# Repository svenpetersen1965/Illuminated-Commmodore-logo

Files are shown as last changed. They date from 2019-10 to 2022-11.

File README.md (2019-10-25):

# Illuminated-Commodore-logo
This is, what you need for your hobby retro computer projects: a Commodore logo, which is illuminated with two LEDs!

This project consists out of a 3D printed logo and a PCB that contains the LEDs and limiting resistors. 

The 3D print is made from three parts:
1. The illuminated body, which is printed with transparent PLA
2. A face plate
3. A reflector

The transparent part is printed with 100% infill (important!). I have printed it upright (on the side with the LED holes). 

There are two types of face plates: one with rounded corners and one without. It should be printed from a material, that is not any translucent. Black is a good color. White is not so suitable. 

The orientation of the reflector while printng is not so important. It should be printed with a white filament.

The Fusion 360 design is contained in this project.

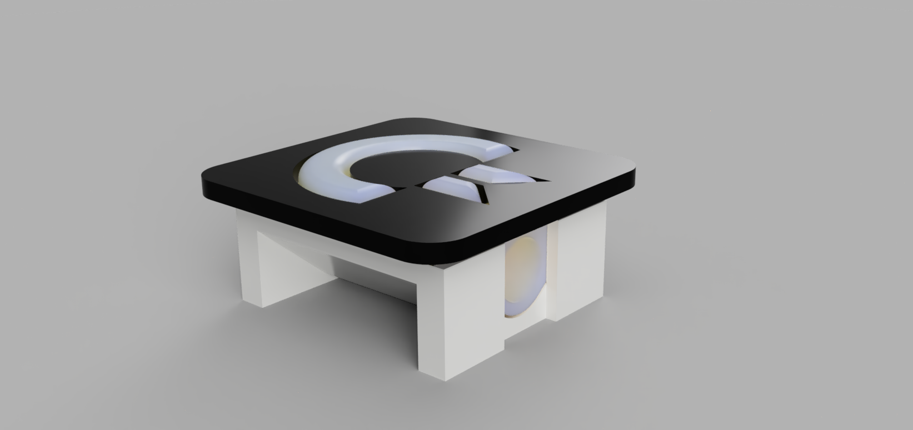
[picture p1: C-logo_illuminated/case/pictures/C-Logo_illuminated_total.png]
Commodore Logo


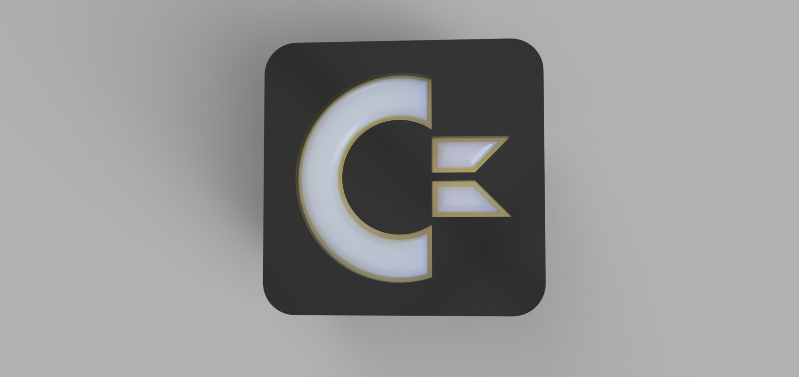
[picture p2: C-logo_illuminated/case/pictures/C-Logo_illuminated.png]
Commodore Logo


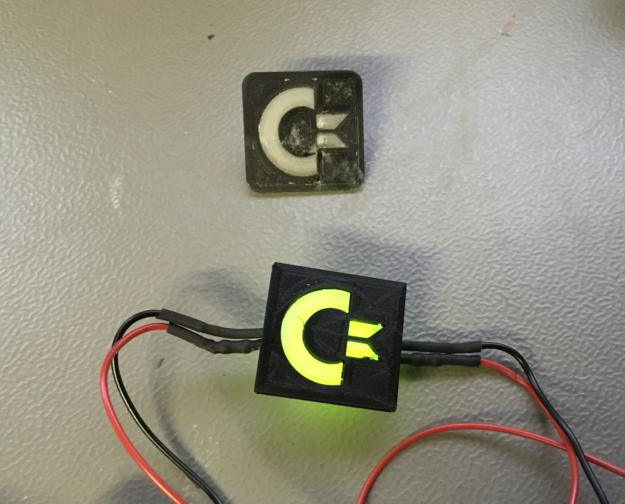
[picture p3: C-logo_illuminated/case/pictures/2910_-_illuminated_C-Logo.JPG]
Commodore Logo


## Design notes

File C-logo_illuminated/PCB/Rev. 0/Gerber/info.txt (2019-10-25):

      
       Board: C-logo
       Rev.:  0
  
       Files:
       ======
  
       All Gerber files are generated in extended gerber format (RS274X)
       *.TOP        : Film top copper
       *.BOT        :  -"- bottom copper
       *.STC        :  -"- top soldermask 
       *.STS        :  -"- bottom soldermask
       *.PLC        :  -"- silk screen top
       *.PLS        :  -"- silk screen bottom
       *.DK         : Drills plated Through (Excellon)
       *.NDK        : Drills not plated Through (Excellon)
       *.OUT        : Board outline

       Board Size:
       ===========
       Length     :   30.0 mm
       Width      :   25.4 mm
       Thickness  :   1.6 mm
       Material   :   FR 4
       Copper     :   35 um
       Surface    :   HASL
       
       Remarks:
       ========
       Width >= 8mil
       Distance >= 6mil
       Drill >= 0.6mm

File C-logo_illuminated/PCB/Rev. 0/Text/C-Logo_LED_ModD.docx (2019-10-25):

Illuminated Commodore Logo Rev. 0
Module description

The Commodore Logo is a sort of fan art and the purpose is the use in hobby projects. A transparent 3D printed body is illuminated with two LEDs and masked with a face plate, that is designed to the measures defined in a document about the Commodore C= logo.

The PCB contains two 5mm LEDs, which are sufficient to illuminate the logo. These LEDs require a current limiting resistor each, which is also contained on the PCB.

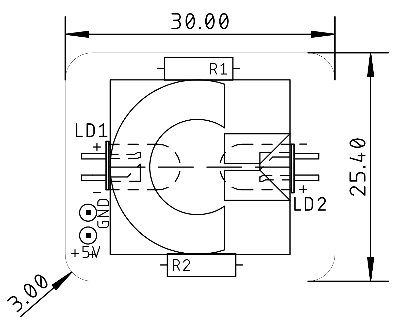
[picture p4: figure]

Figure 1: Dimensions of the PCB

For 5V supply voltage and a standard red, green or yellow LED, a value of 330Ω is sufficient. For other LEDs, like a blue or white LED, or other supply voltages or currents, the resistor value has to be calculated.

R_(LED) =(U_(supply) -U_(f, LED))/(I_(f,LED))

RLED: current limiting resistor for the LED
Usupply: Supply voltage
Uf,LED: Forward voltage of the LED
If, LED: Forward current of the LED

The forward voltage and current can be found in the data sheet of the LED. That is the voltage drop over the LED, when it is conducting and the current should be below the maximum rating. A typical value for a standard LED is Uf, LED is 1.8V and for the current If,LED is 10mA. This results in

R_(LED) =(5V-1.8V)/(0.010A)=320Ω≈330Ω

The available resistor value closest to 320Ω is 330Ω. The resistors do not require a very accurate value, so it is no problem to use what is available. A range of ±10% is ok for this purpose.

A blue LED with a forward voltage of 3.2V and a forward current of 20mA will require a forward resistor, that is

R_(LED) =(5V-3.2V)/(0.020A)=90Ω≈91Ω

A 91Ω resistor is sufficient. Notice: The forward voltages of blue LEDs are varying and it is required to look it up for the specific LED. The same applies for white LEDs.

C-Logo_LED_ModD.docx 25.10.2019 11:45 Drafted by Sven Petersen Page 2 of 2 Doc.-No.: 000-6-00-00

C-Logo_LED_ModD.docx 25.10.2019 11:45 Drafted by Sven Petersen Page 1 of 1 Doc.-No.: 135-6-01-00

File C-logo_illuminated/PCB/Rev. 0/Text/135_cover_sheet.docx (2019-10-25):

Project Documentation

Illuminated Commodore Logo

Project number: 135

Revision: 0

Date: 25.10.2019

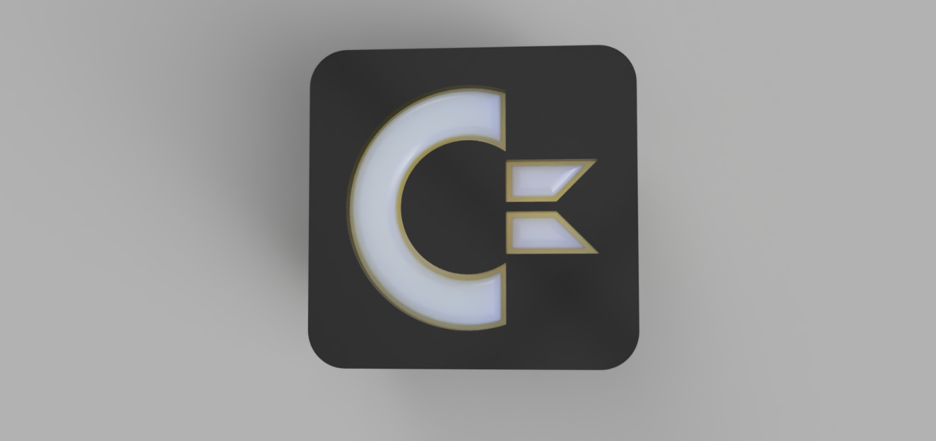
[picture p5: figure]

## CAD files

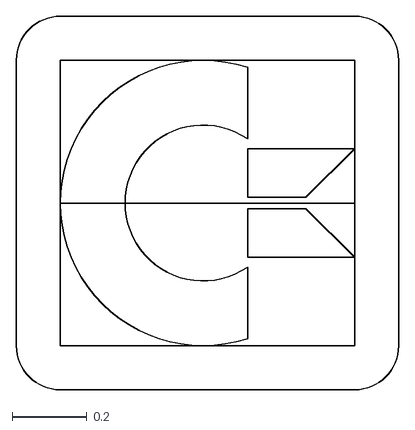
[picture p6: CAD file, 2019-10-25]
C-logo_illuminated/case/dxf/c-logo_used.DXF
1.02 x 1.00

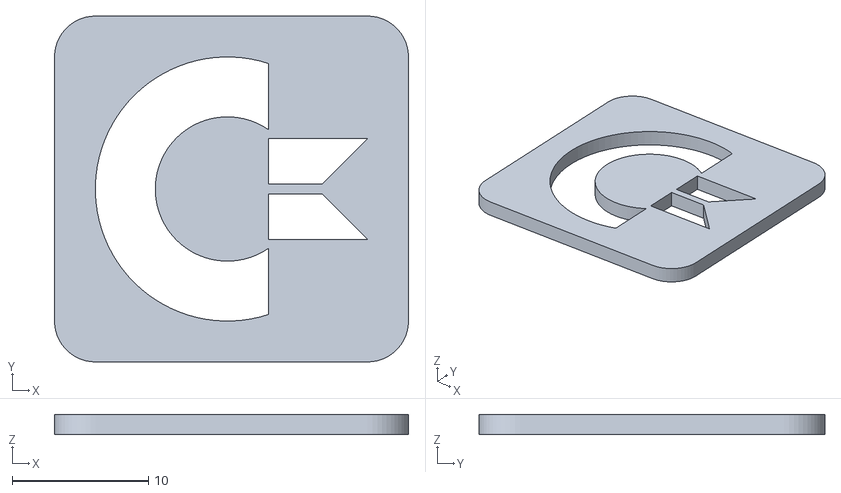
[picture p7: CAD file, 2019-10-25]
C-logo_illuminated/case/stl/face plate rounded.stl
26.0 x 25.4 x 1.50

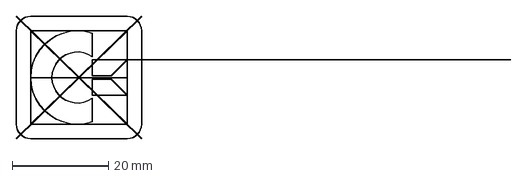
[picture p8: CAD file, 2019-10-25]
C-logo_illuminated/case/dxf/c-logo.dxf
102.6 x 25.4 mm

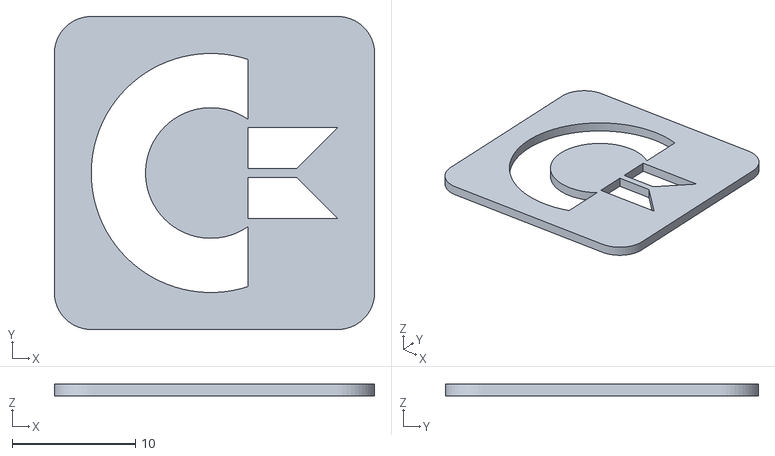
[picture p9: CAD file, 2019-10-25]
C-logo_illuminated/case/stl/panel.stl
26.0 x 25.4 x 1.00

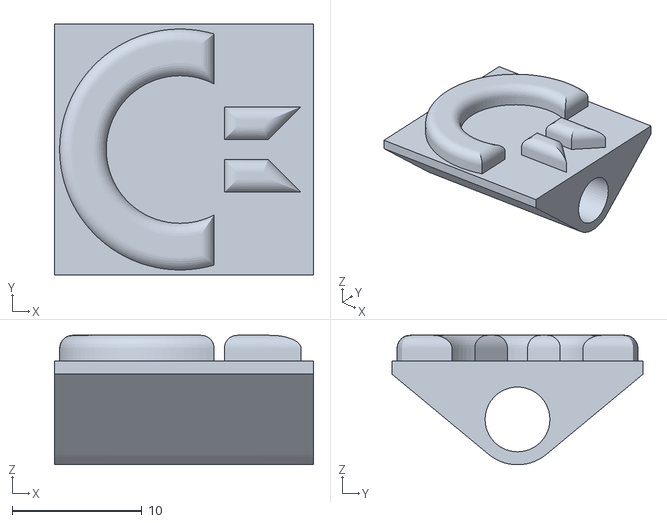
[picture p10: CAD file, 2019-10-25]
C-logo_illuminated/case/stl/illuminated body.stl
20.0 x 19.4 x 10.0

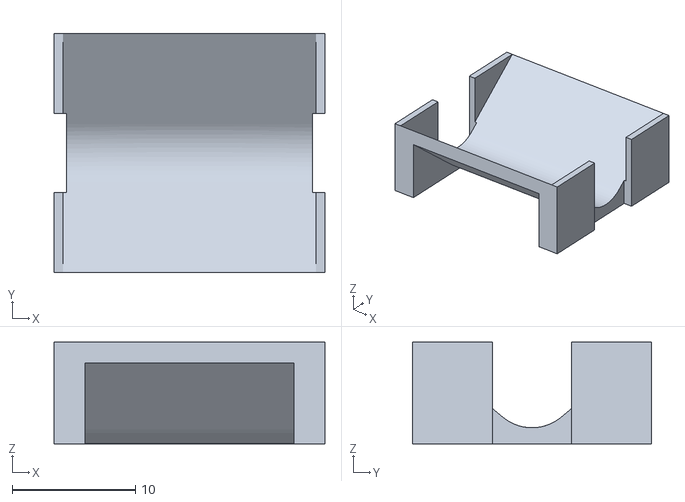
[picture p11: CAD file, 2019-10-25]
C-logo_illuminated/case/stl/reflector.stl
22.0 x 19.4 x 8.24

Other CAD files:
C-logo_illuminated/case/stl/face plate 1.5.stl
C-logo_illuminated/case/fusion 360/C-Logo_illuminated v12.f3d

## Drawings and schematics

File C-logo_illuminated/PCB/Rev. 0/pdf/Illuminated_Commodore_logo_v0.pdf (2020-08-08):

# Project Documentation

## Illuminated Commodore Logo

## Project number: 135

## Revision: 0

## Date: 25.10.2019

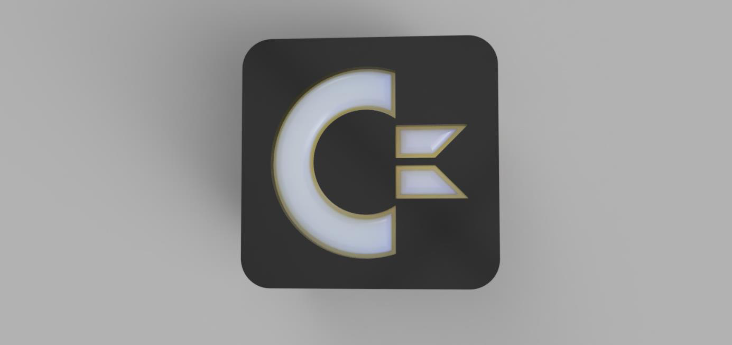
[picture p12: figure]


C-Logo_LED_ModD.docx | | 25.10.2019 11:45
Drafted by Sven Petersen | Page 1 of 1 | Doc.-No.: 135-6-01-00

### Illuminated Commodore Logo Rev. 0

### Module description

The Commodore Logo is a sort of fan art and the purpose is the use in hobby projects. A transparent 3D printed body is illuminated with two LEDs and masked with a face plate, that is designed to the measures defined in a document about the Commodore C= logo.

The PCB contains two 5mm LEDs, which are sufficient to illuminate the logo. These LEDs require a current limiting resistor each, which is also contained on the PCB.

Figure 1: Dimensions of the PCB
For 5V supply voltage and a standard red, green or yellow LED, a value of 330Ω is sufficient. For other LEDs, like a blue or white LED, or other supply voltages or currents, the resistor value has to be calculated.

# RLED =

# Usupply − Uf,LED

# If,LED

RLED: current limiting resistor for the LED Usupply: Supply voltage
Uf,LED: Forward voltage of the LED
If, LED: Forward current of the LED

The forward voltage and current can be found in the data sheet of the LED. That is the voltage drop over the LED, when it is conducting and the current should be below the maximum rating. A typical value for a standard LED is Uf, LED is 1.8V and for the current If,LED is 10mA. This results in

# RLED =

5V − 1.8V

# 0.010A = 320Ω ≈ 330Ω

The available resistor value closest to 320Ω is 330Ω. The resistors do not require a very accurate value, so it is no problem to use what is available. A range of ±10% is ok for this purpose.

A blue LED with a forward voltage of 3.2V and a forward current of 20mA will require a forward resistor, that is

# RLED =

5V − 3.2V
0.020A

= 90Ω ≈ 91Ω

A 91Ω resistor is sufficient. Notice: The forward voltages of blue LEDs are varying and it is required to look it up for the specific LED. The same applies for white LEDs.

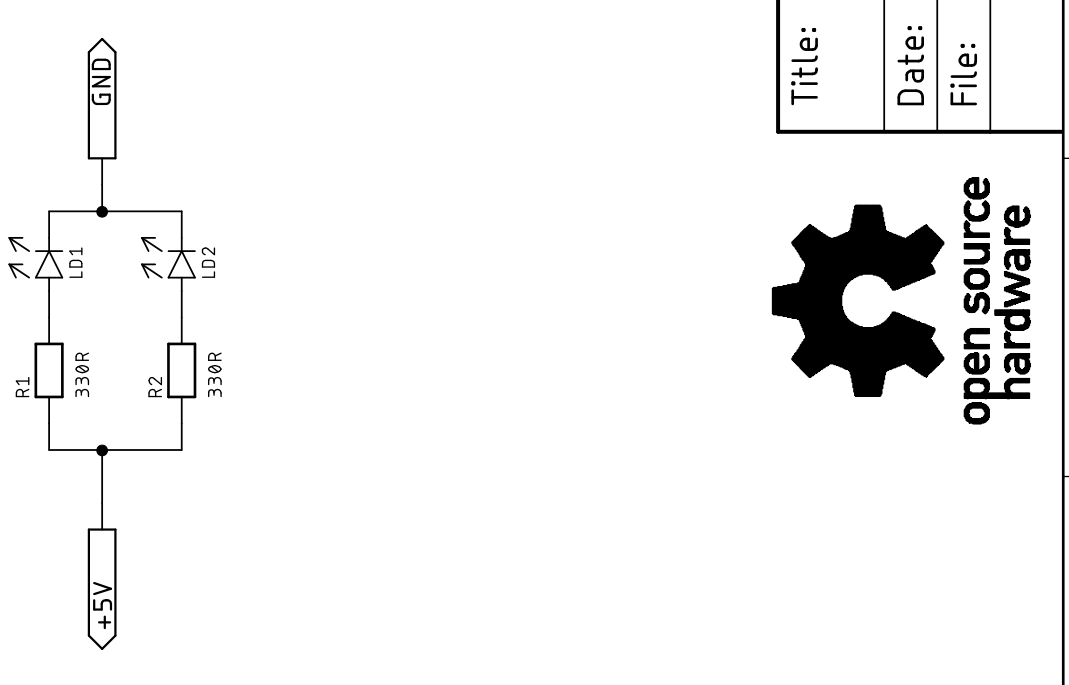
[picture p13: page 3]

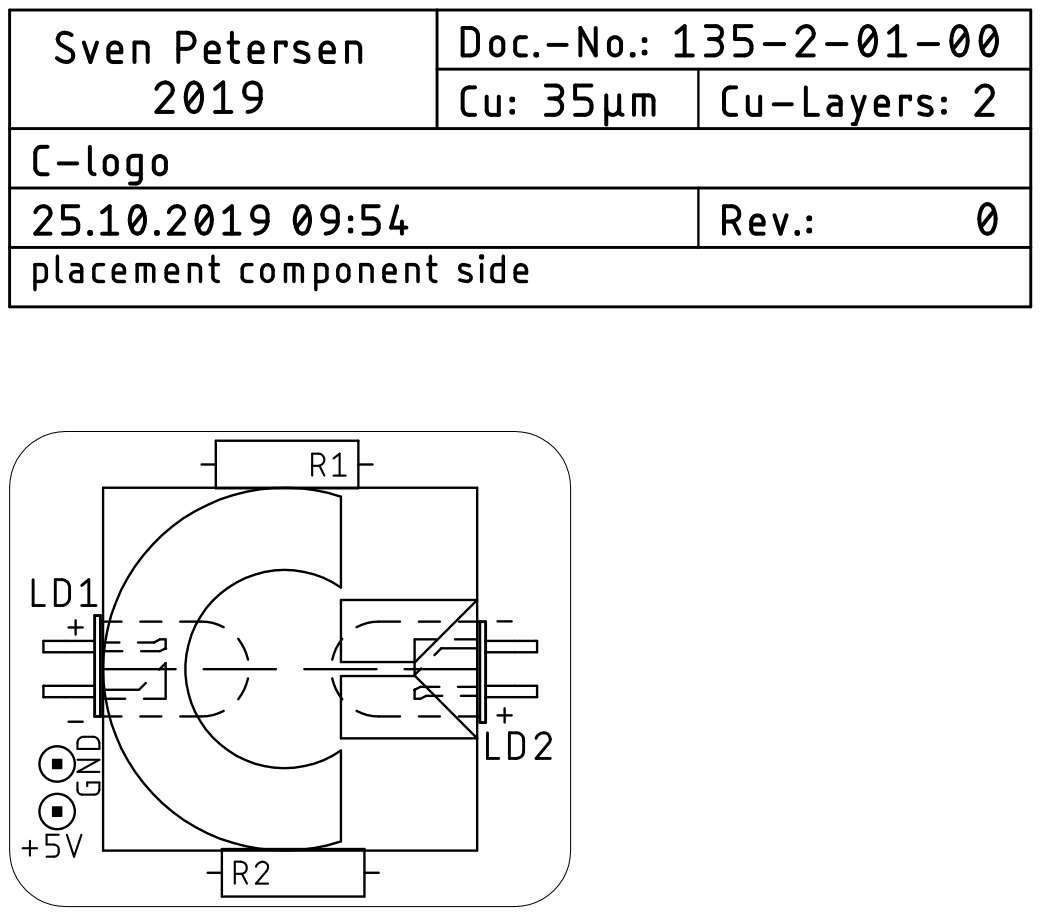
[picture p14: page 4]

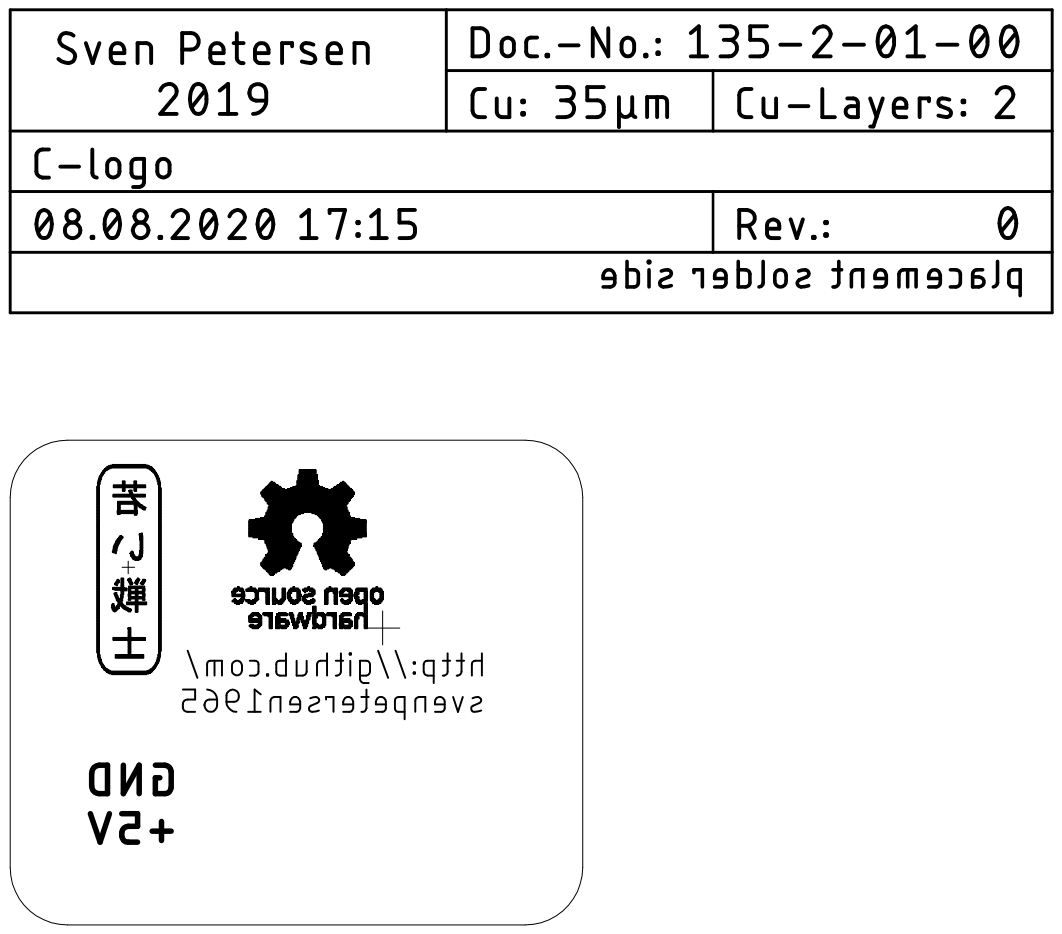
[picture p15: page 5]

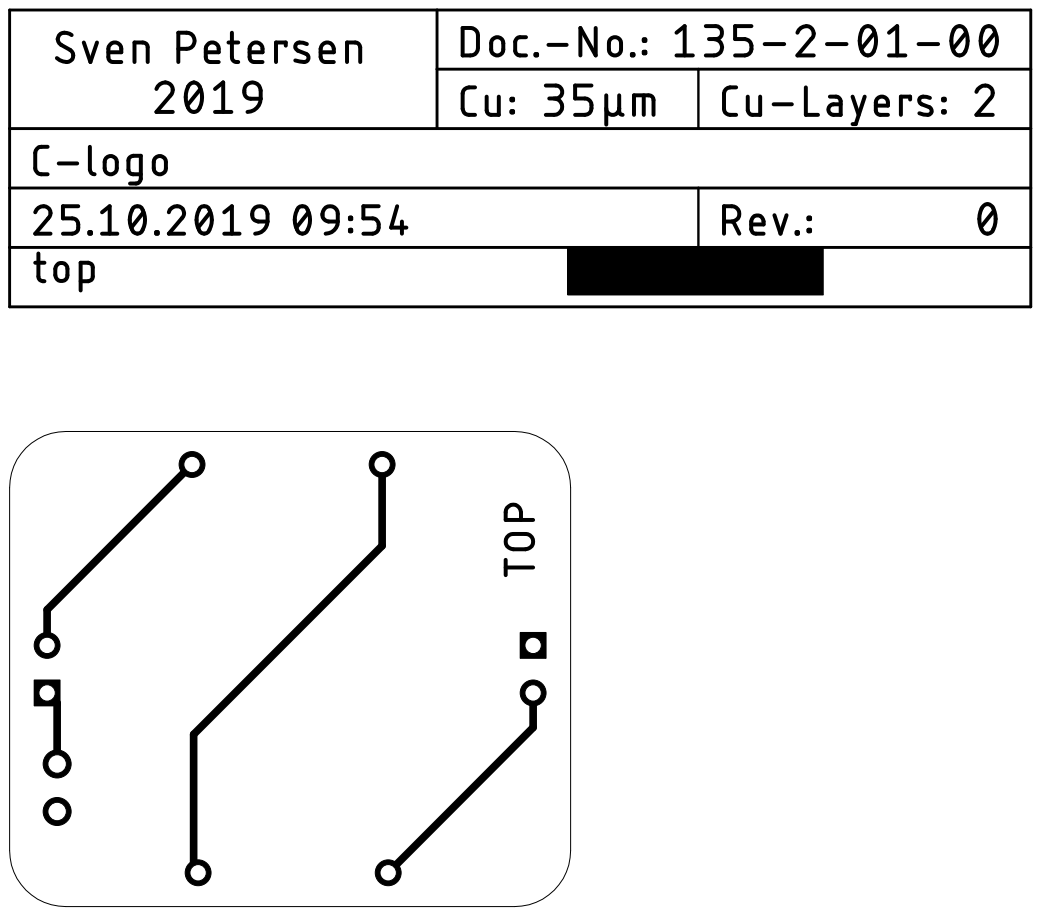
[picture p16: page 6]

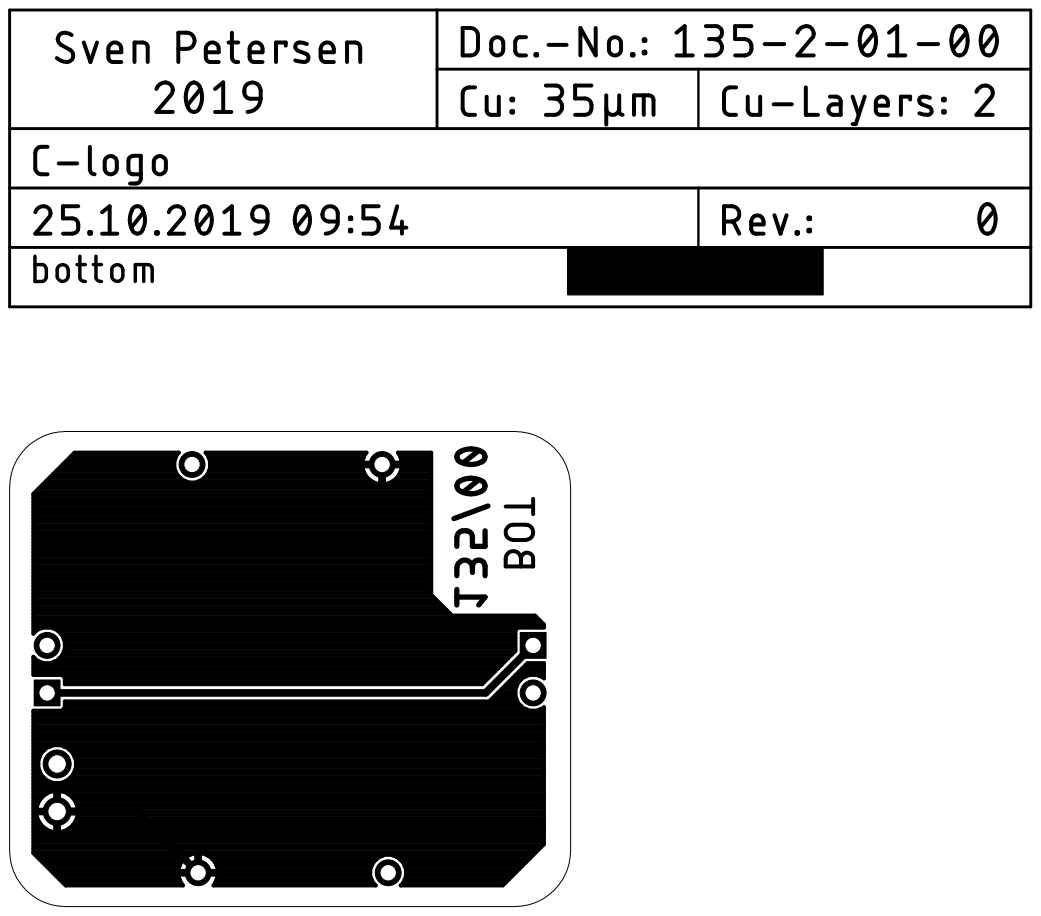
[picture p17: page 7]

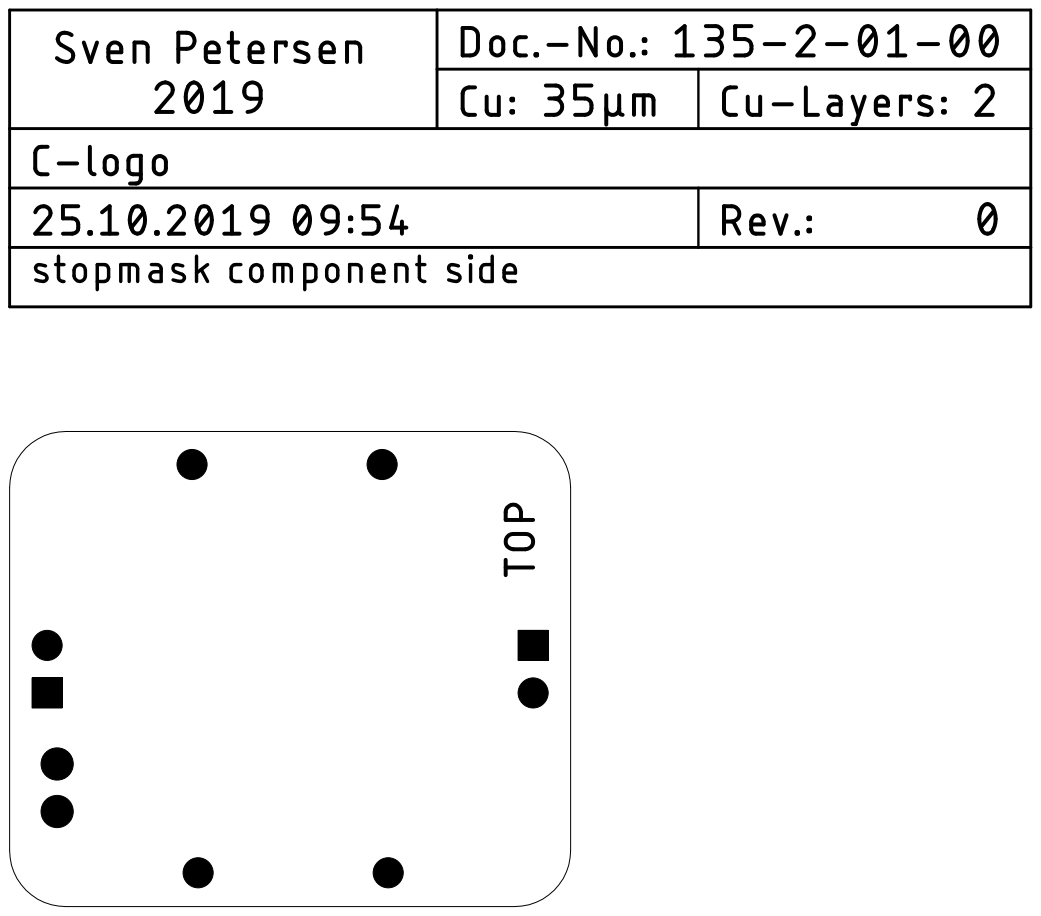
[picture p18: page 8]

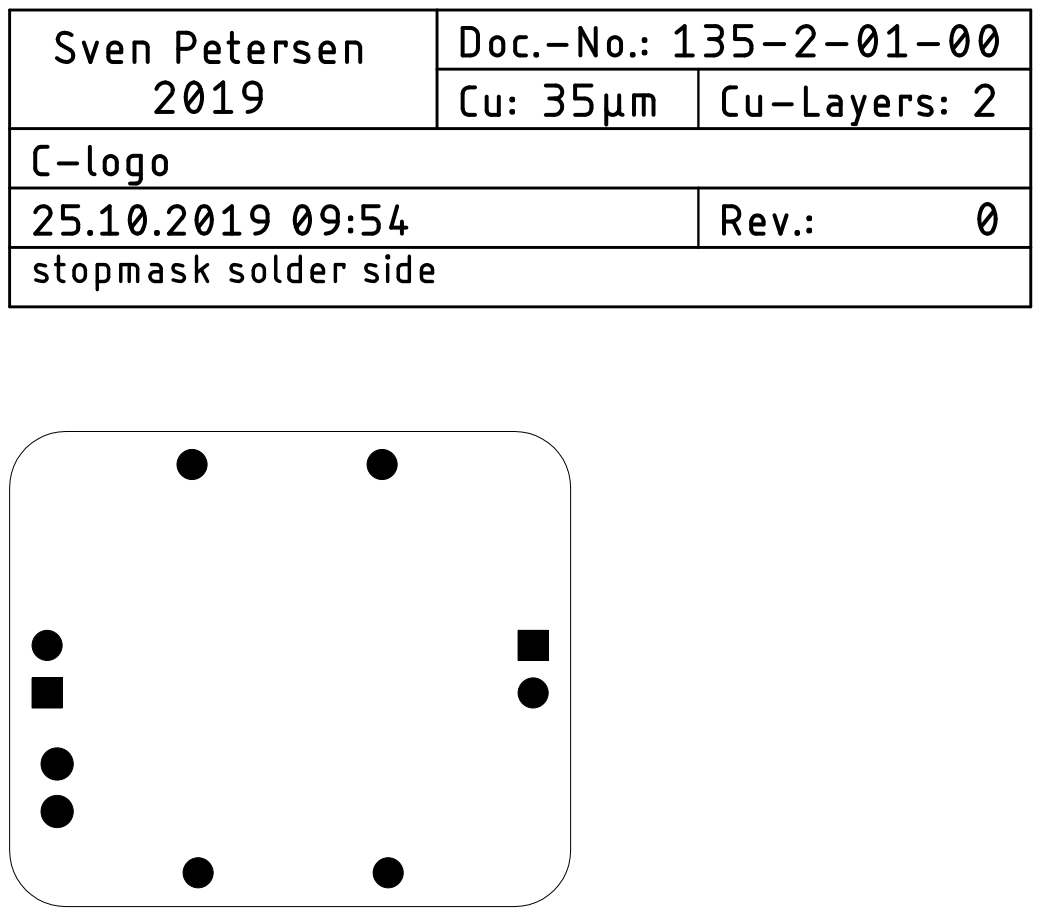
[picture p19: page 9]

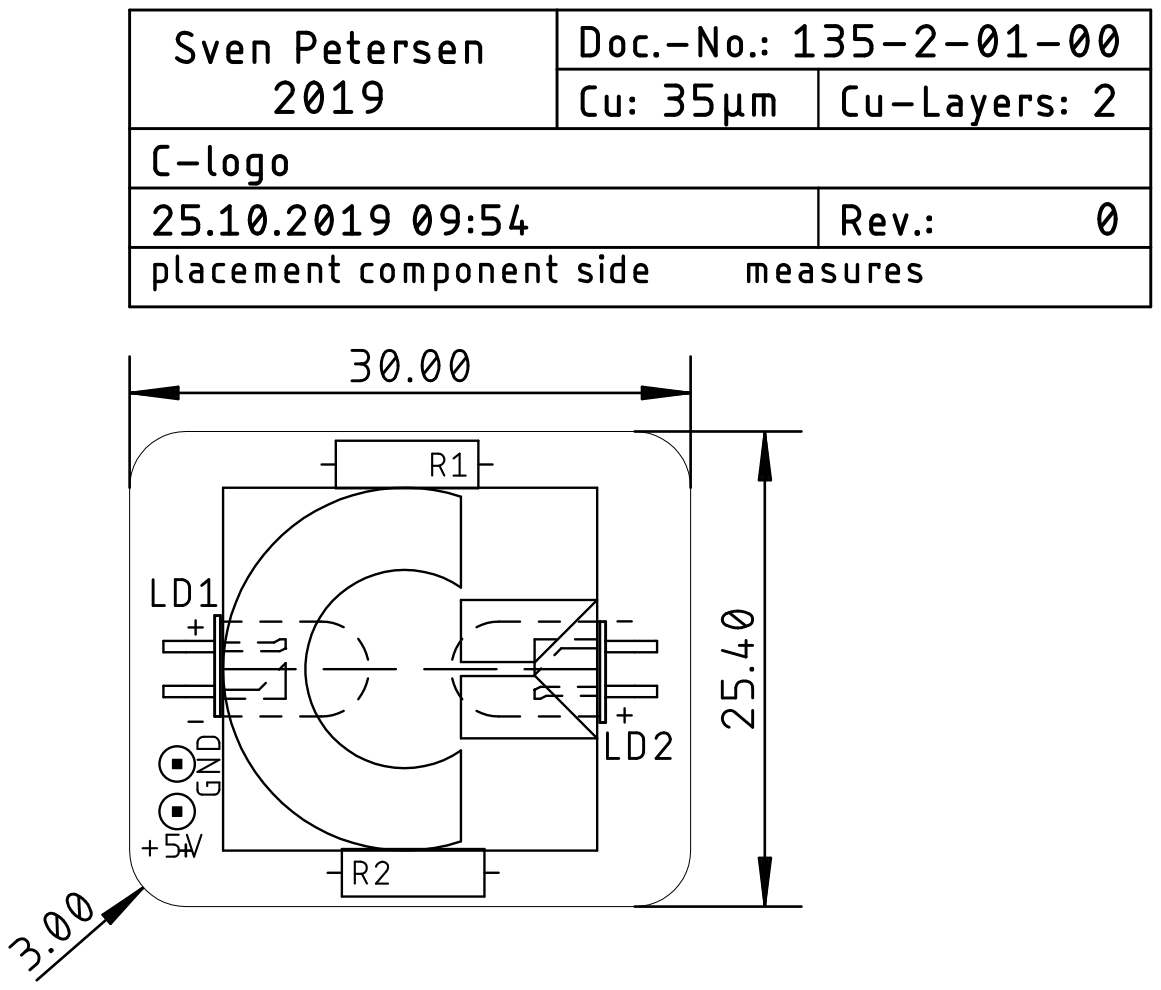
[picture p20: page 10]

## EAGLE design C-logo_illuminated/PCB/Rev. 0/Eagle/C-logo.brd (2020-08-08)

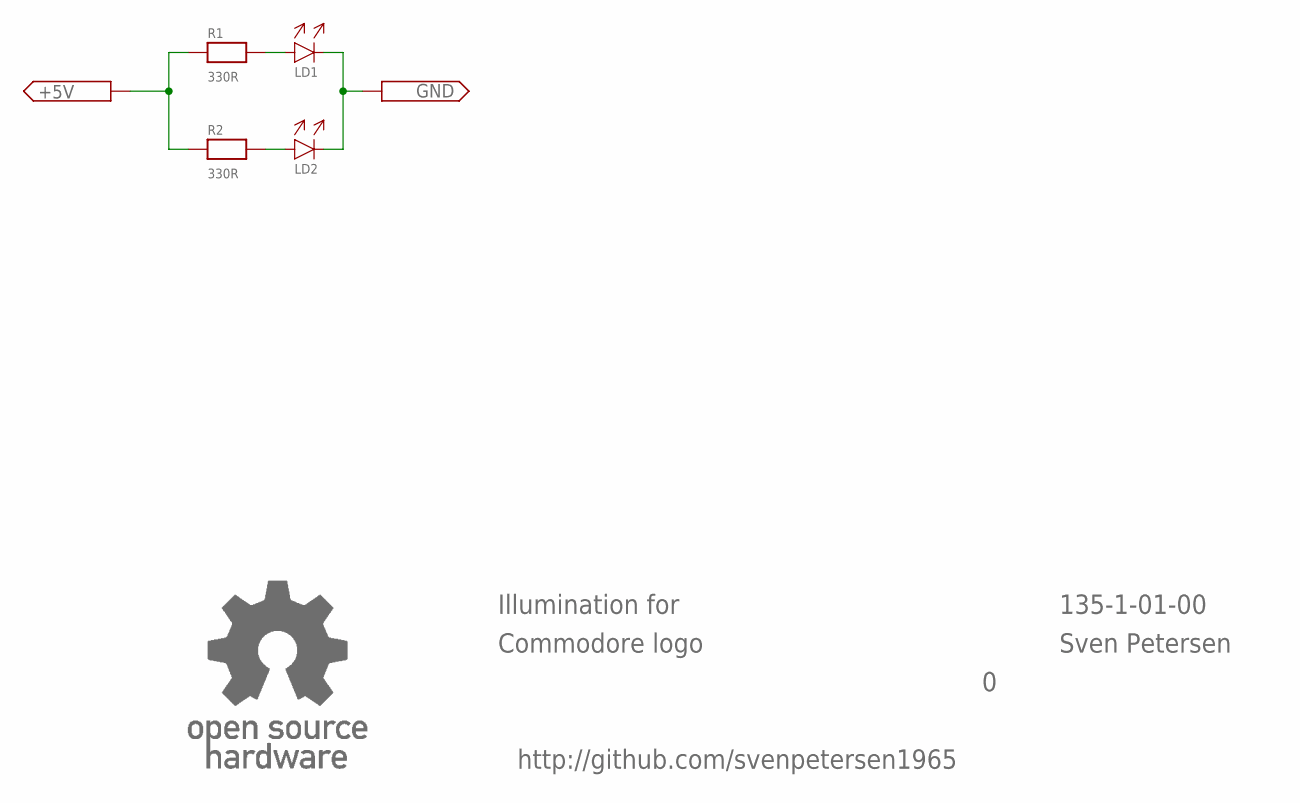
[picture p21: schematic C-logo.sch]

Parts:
+5V: PAD1,0/AUTO; 1.0/AUTO
GND: PAD1,0/AUTO; 1.0/AUTO
LD1, LD2: 5MM90°INSERTED; 5MM_90°
R1, R2: 330R; R-10
U$5: OPEN_SOURCE_HW; OPENHW

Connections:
GND: +5V.1, R1.1, R2.1
unnamed: LD1.A, R1.2
unnamed: LD2.A, R2.2
unnamed: GND.1, LD1.K, LD2.K

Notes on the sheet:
Illumination for
Commodore logo
135-1-01-00
Sven Petersen
http://github.com/svenpetersen1965

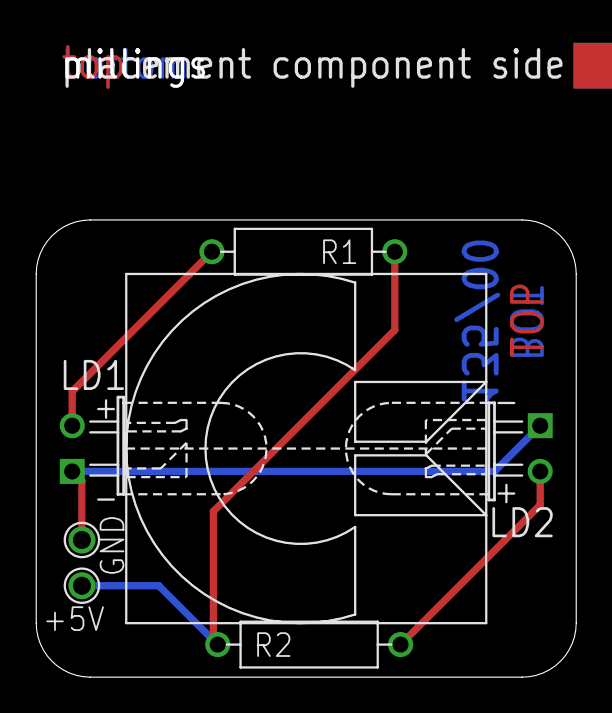
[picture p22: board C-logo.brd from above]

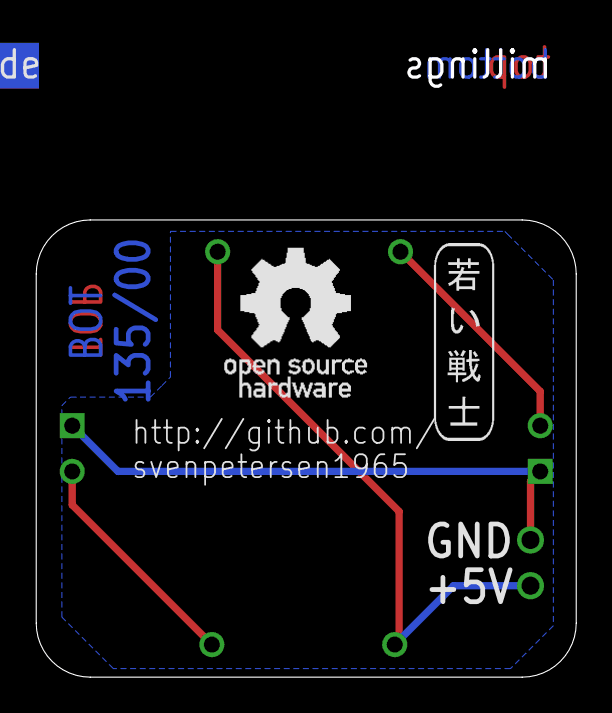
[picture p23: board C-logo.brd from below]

Board: 2 copper layers, 30.0 x 25.4 mm, 10 parts (2 on the bottom side), 4 nets.

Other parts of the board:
U$2: 2LAYER
U$3: SVEN_TAG
U$4: PCB-TITLE/
